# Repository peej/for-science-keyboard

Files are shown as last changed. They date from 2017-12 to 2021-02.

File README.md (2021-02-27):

For Science is a 46 key ortholinear split keyboard PCB with a 3 key thumb cluster.

The goal of this project is to build a usable split keyboard with a PCB case within the 100x100mm cheap PCB size limit offered by some PCB manufactuers. Designed to be easy to build, it only supports serial communication over a TRRS cable and no LED support. The PCB is reversible, meaning that you need two of the same PCB to create a full keyboard.

Final assembled keyboard
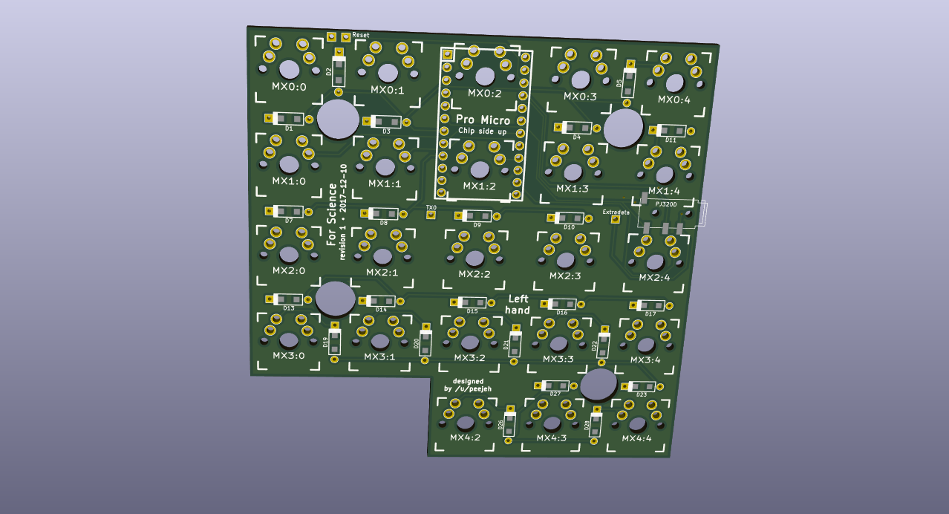
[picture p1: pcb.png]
PCB render from KiCad

PCBs in white and green

# Bill of Materials (BOM)

* 2 PCBs
* 46 MX compatible switches.
* 46 1n4148 diodes.
* 2 Pro Micro controllers.
* 2 PJ320D 3.5mm TRRS jacks.
* TRRS cable and micro USB cable.
* 2 plate PCBs and 2 base PCBs.
* 8 M2 standoffs (15mm)
* 16 M2 screws (6mm)
* 46 MX compatible key caps.

# Ordering PCBs

PCBs can be manufactuered by a variety of online PCB fabricators, some have special offers for PCBs under 100mm square, so shop around. You can use [PCBShopper](https://pcbshopper.com/) to search for the best price.

The 3 zip files in the gerber directory contain the gerber files your fabricator will need to make the main PCB [for-science-pcb.zip](https://github.com/peej/for-science-keyboard/blob/master/gerber/for-science-pcb.zip) and the plate [for-science-plate.zip](https://github.com/peej/for-science-keyboard/blob/master/gerber/for-science-plate.zip) and base  [for-science-base.zip](https://github.com/peej/for-science-keyboard/blob/master/gerber/for-science-base.zip) PCBs.

When uploading the gerber zip files, use the default PCB settings. The plate PCB thickness should be 1.6mm for the switches to snap into the plate securely.

# Construction

* Solder the diodes onto the underside of each PCB.
* Solder on the Pro Micro headers (or a 24 pin DIP socket) onto the underside of each PCB, do not solder on the Pro Micros yet.
* Solder the PJ320D TRRS sockets onto the underside of each PCB. These are SMD components rather than through-hole so as not to interfere with the switch locations.
* Insert the switches into the plate and then into the top of the PCBs. Insert all the switches and ensure that the pins of each switch are correctly coming through the board and are not bent under the PCB.
* Solder all the switch pins.
* Solder on the Pro Micros, ensure that you get them the correct way around and with the correct side up, the chip side should be face down on the left hand PCB and chip side up on the right hand PCB.
* Attach the standoffs to the plate PCB with the screws.
* Attach the base to the standoffs.
* Connect the halves together with the TRRS cable.
* Flash both Pro Micros with the firmware, see the [QMK documentation](http://qmk.fm/) on how to build and flash the firmware.

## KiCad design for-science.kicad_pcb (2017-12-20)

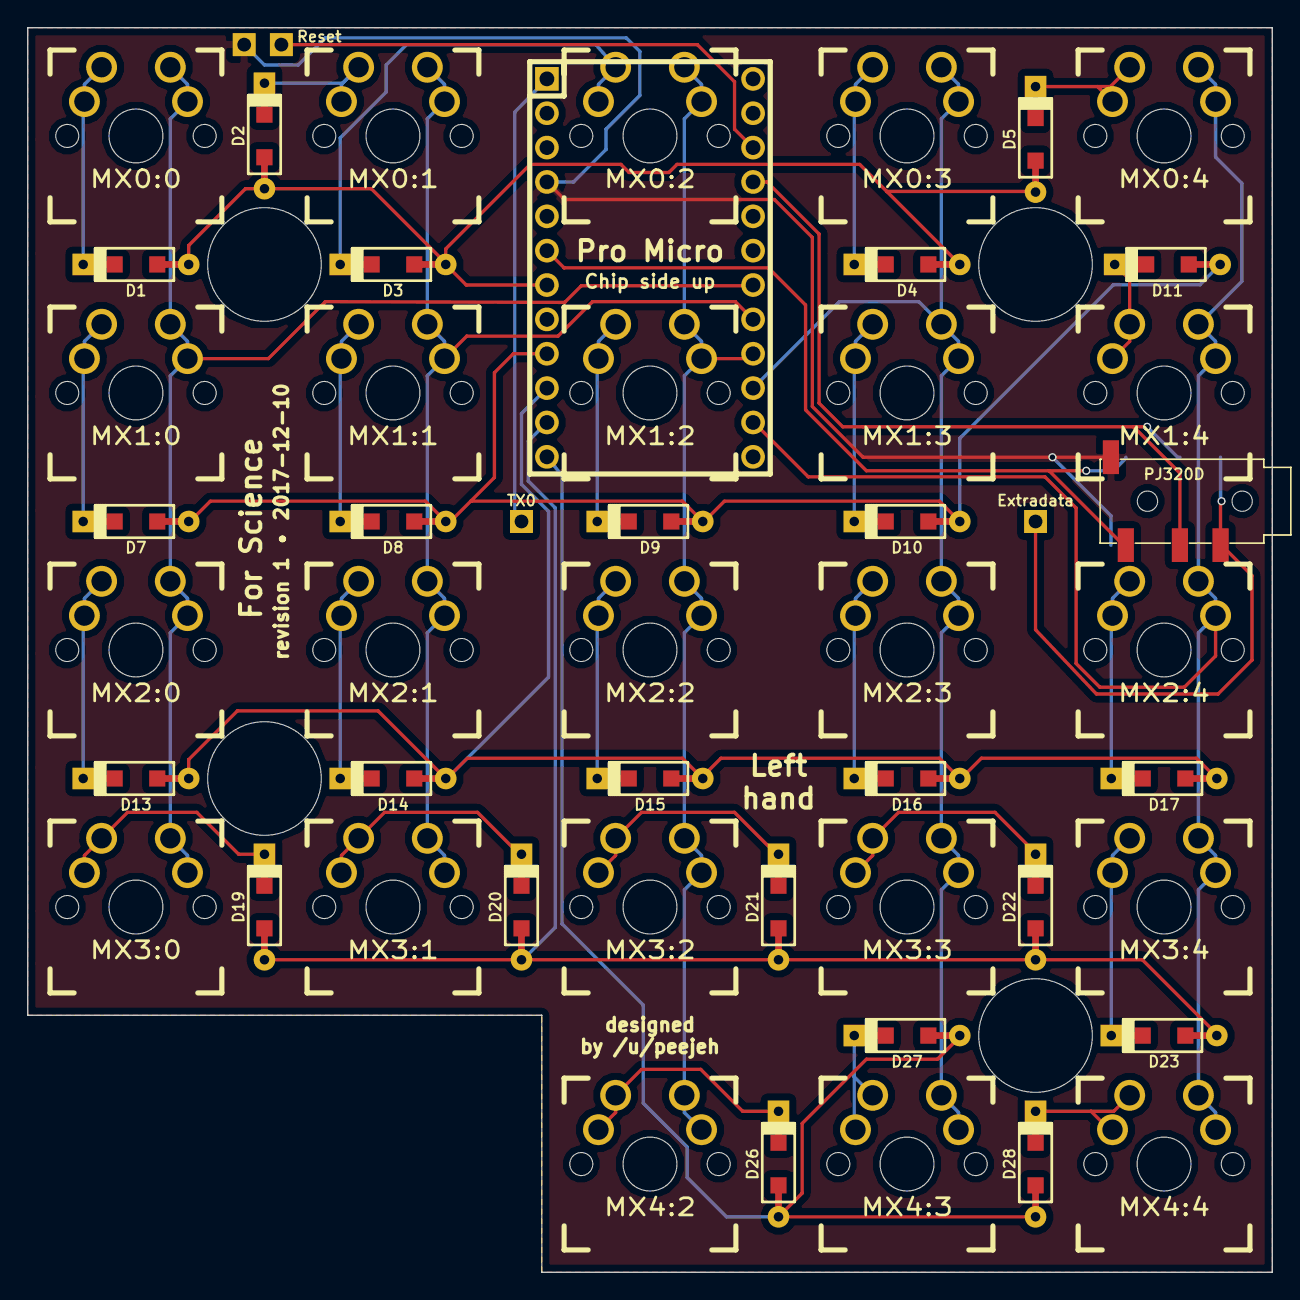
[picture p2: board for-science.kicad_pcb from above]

Board: 2 copper layers, 92.0 x 92.0 mm, 57 parts (1 on the bottom side), 39 nets.

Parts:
D1, D2, D3, D4, D5, D7, D8, D9, D10, D11, D13, D14, D15, D16, D17, D19, D20, D21, D22, D23, D26, D27, D28: DIODE; D_SOD123_axial
EXTRADATA1: Extradata; PIN_1_SQUARE
GROUND1: Ground; PIN_1_SQUARE
J1: TRRS; PJ320D_3.5mm_Jack_SMD
J2: TRRS; PJ320D_3.5mm_Jack_SMD_Flip
M8, M8#2, M8#3, M8#4: MountingHole_8.4mm_M8
MX0:0: MX0:9; MX_DoubleSided
MX0:1: MX0:8; MX_DoubleSided
MX0:2: MX0:7; MX_DoubleSided
MX0:3: MX0:6; MX_DoubleSided
MX0:4: MX0:5; MX_DoubleSided
MX1:0: MX1:9; MX_DoubleSided
MX1:1: MX1:8; MX_DoubleSided
MX1:2, MX1:4: MX1:7; MX_DoubleSided
MX1:3: MX1:6; MX_DoubleSided
MX2:0: MX2:9; MX_DoubleSided
MX2:1: MX2:8; MX_DoubleSided
MX2:2: MX2:7; MX_DoubleSided
MX2:3: MX2:6; MX_DoubleSided
MX2:4: MX2:5; MX_DoubleSided
MX3:0: MX3:9; MX_DoubleSided
MX3:1: MX3:8; MX_DoubleSided
MX3:2: MX3:7; MX_DoubleSided
MX3:3: MX3:6; MX_DoubleSided
MX3:4: MX3:5; MX_DoubleSided
MX4:2: MX4:7; MX_DoubleSided
MX4:3: MX4:6; MX_DoubleSided
MX4:4: MX4:5; MX_DoubleSided
RESET1: Reset; PIN_1_SQUARE
TX0: TX0; PIN_1_SQUARE
U1: ARDUINO_PRO_MICRO

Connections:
/Col0: MX0:0.1, MX1:0.1, MX2:0.1, MX3:0.1, U1.18
/Col1: MX0:1.1, MX1:1.1, MX2:1.1, MX3:1.1, U1.17
/Col2: MX0:2.1, MX1:2.1, MX2:2.1, MX3:2.1, MX4:2.1, U1.16
/Col3: MX0:3.1, MX1:3.1, MX2:3.1, MX3:3.1, MX4:3.1, U1.15
/Col4: MX0:4.1, MX1:4.1, MX2:4.1, MX3:4.1, MX4:4.1, U1.14
/Row0: D1.2, D2.2, D3.2, D4.2, D5.2, U1.7
/Row1: D7.2, D8.2, D9.2, D10.2, D11.2, U1.9
/Row2: D13.2, D14.2, D15.2, D16.2, D17.2, U1.10
/Row3: D19.2, D20.2, D21.2, D22.2, D23.2, U1.11
/Row4: D26.2, D27.2, D28.2, U1.12
GND: GROUND1.1, J1.4, J2.4, U1.4
unnamed: D1.1, MX0:0.2
unnamed: D2.1, MX0:1.2
unnamed: D3.1, MX0:2.2
unnamed: D4.1, MX0:3.2
unnamed: D5.1, MX0:4.2
unnamed: D7.1, MX1:0.2
unnamed: D8.1, MX1:1.2
unnamed: D9.1, MX1:2.2
unnamed: D10.1, MX1:3.2
unnamed: D11.1, MX1:4.2
unnamed: D13.1, MX2:0.2
unnamed: D14.1, MX2:1.2
unnamed: D15.1, MX2:2.2
unnamed: D16.1, MX2:3.2
unnamed: D17.1, MX2:4.2
unnamed: D19.1, MX3:0.2
unnamed: D20.1, MX3:1.2
unnamed: D21.1, MX3:2.2
unnamed: D22.1, MX3:3.2
unnamed: D23.1, MX3:4.2
unnamed: D26.1, MX4:2.2
unnamed: D27.1, MX4:3.2
unnamed: D28.1, MX4:4.2
unnamed: EXTRADATA1.1, J1.3, J2.3
unnamed: J1.1, J2.1, U1.6
unnamed: RESET1.1, U1.22
unnamed: TX0.1, U1.1
VCC: J1.2, J2.2, U1.21

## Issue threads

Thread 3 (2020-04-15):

Mini group buy?

jdayton3, 2020-04-15:
Hey! I have been eyeing this keyboard for a while, and I went to place an order for it the other day and realized that shipping is pretty expensive for small orders of PCBs. I started mulling over the idea of doing a small group buy so shipping costs could be divided among several orders, and I thought that before I moved forward with that, I should contact you and see how you feel about it, since it's your keyboard!

Let me know what you think - you can contact me on Reddit (u/knot-a-robot) or find my other contact info at my woefully out-of-date personal website, http://jdaytn.com/

peej, 2020-04-15:
No problem. The keyboard is pretty unusable but it's a fun little project.

JLCPCB do pretty cheap shipping for 5 sub-100x100 PCBs if you pick their slow shipping.

jdayton3, 2020-04-15:
Awesome, thanks! I've noticed an uptick in 10-column keebs lately (Little_Foot, GergoPlex, Atreus, to name a few) and thought it'd be neat to see what all the rage is about on the cheap!

jdayton3, 2020-04-16:
Oh hey, what length of M2 screws / standoffs does this require?

jdayton3, 2020-04-17:
Wasn't sure if you'd get notifications for a closed issue, so reopening

peej, 2020-04-17:
The standoffs need to be long enough to clear the Promicro chip side up, so it depends on how closely you can solder it to the PCB. If you use the standard Promicro headers then 8mm standoffs should provide enough of room, if you forgo the headers and solder the Promicro closer to the PCB you could probably get away with 5 or 6mm.

The screws need to be short enough to screw into the standoffs without hitting the opposing screw from the other side, so less than half the standoff length plus the PCB thickness.

Closed 2020-06-17.

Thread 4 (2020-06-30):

Plate failed preflight check at JLCPCB

bmordue, 2020-06-30:
I uploaded https://github.com/peej/for-science-keyboard/blob/master/gerber/for-science-plate.zip to JLPCB with PCB thickness 1.6mm.
I received a message from JLCPCB:
"Please kindly note that the connection tabs between the slots and the board edge is too small in you file which will make the board broken easily. In order to ensure the board quality, we advise you to enlarge the connection tabs to 3mm at least."

peej, 2020-06-30:
I ordered mine from AllPCB and didn't have a problem ordering with these gerbers or with the resulting plates. I guess JLCPCB have a different set of checks.

I think you'll be fine but you can always adjust the plate file to make it bigger if you feel the need.

bmordue, 2020-07-03:
Thanks for the reply!
I'll try tweaking the plate. Just wanted to flag it up.

Closed 2020-07-03.

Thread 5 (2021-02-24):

"2M" screws and standoffs

semilin, 2021-02-24:
Hi, I was trying to gather the parts to see how much it would cost to assemble this, and I was stuck trying to figure out where to get the 2M screws and standoffs. It seems I either get results for 2 millimeter ones, or "M2" screws. Are either of these what I am looking for? Sorry if this is a trivial question.

peej, 2021-02-24:
Hi, yes sorry this is incorrect in the documentation, it should read M2. Best of luck with your build.

Closed 2021-07-08.

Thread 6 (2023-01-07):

Do I need pull-up resistors?

Matheus-de-Souza, 2023-01-07:
I build the keyboard, but it doesn't works with the two halfs together. Do I need to put the pull-up resistor?

peej, 2023-01-07:
No, it should be using a serial connection rather than i2c. It may be that QMK has changed in the last 5 years and the firmware config needs an update if you are building from the latest QMK, but first check that the 3 serial pins are connected correctly so there is continuity through your TRRS cable.

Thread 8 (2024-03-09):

Can the PCB be made compatible to Cherry MX LP switches?

alfaklide, 2024-03-09:
I've got TTC Low Profile switches who's cylinder in the bottom are larger in diameter than hole provided. Also have to make the upper layers with squares little smaller to snap the switches in place

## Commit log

2017-12-14 Add PCB design files
    [for-science.kicad_pcb, for-science.sch]
2017-12-14 Add plate and base design files
    [base.kicad_pcb, plate.kicad_pcb]
2017-12-20 Add gerber files
    [base.kicad_pcb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]
2018-02-06 Add assembled keyboard picture
2021-02-27 Fix standoff/screw size in documentation
